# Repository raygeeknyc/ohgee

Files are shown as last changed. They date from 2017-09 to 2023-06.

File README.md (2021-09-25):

# ohgee
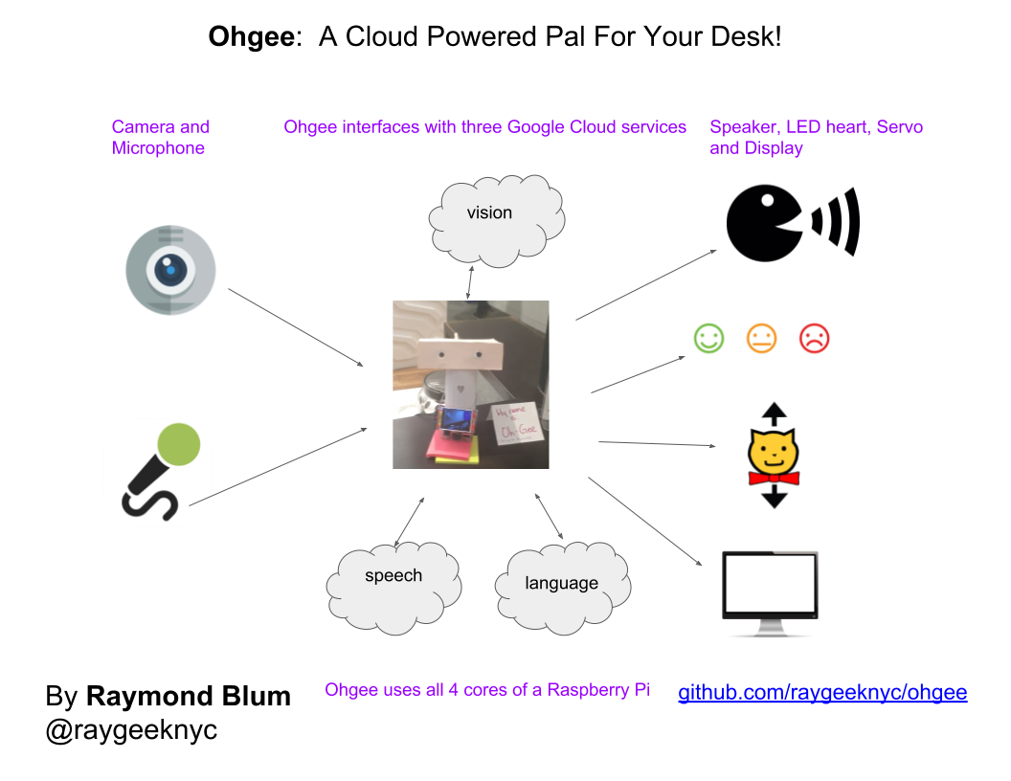
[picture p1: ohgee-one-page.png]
In a nutshell Overview


The OhGee Cloud Services Avatar

A robot that understand speech and face sentiment; it nods, speaks and uses an RGB LED heart to interact with observers.

Ohgee performs local motion detection, sound detection and speech synthesis.

When motion is detected, images are sent to the [Google Cloud Vision service](https://cloud.google.com/vision/) for object detection and labelling.

When sound is detected, the audio stream is sent to the [Google Cloud Speech-to-Text service](https://cloud.google.com/speech-to-text/) for speech recognition.

Any speech transcript returned by the speech service is sent to the [Google Cloud Natural Language service](https://cloud.google.com/natural-language/) for analysis.

Analyzed speech is examined for known key phrases and patterns to which Ohgee selects a random response from an associated set of responses.

Analyzed images are checked for some known labels, if any of those labels are present, Ohgee responds with both incredible wit and tact!
The analyzed images are examined for faces - if any faces are found, Ohgee elides each face with a smiley illustrating their detected sentiment.
If a face is "close enough" Ohgee greets the person and bid them farewell when they depart.

Click on the image to see a quick demo...
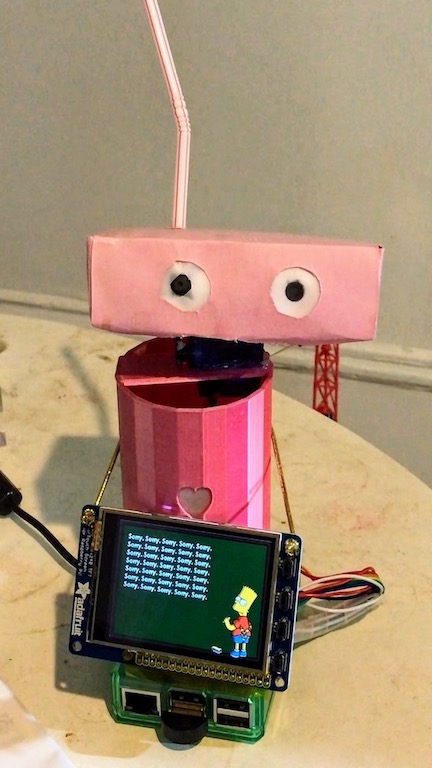
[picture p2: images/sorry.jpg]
demo (https://youtu.be/PBYmpuFzArQ "Ohgee demo")


But wait... there's more!

Since visual and audible "noise" varies widely based on location, Ohgee establishes background levels for sound and motion when starting up.

Ohgee also updates from github at startup and restarts if network connectivity is lost.

Want to know more about any of this? Look at the code!

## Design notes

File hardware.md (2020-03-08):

Screen connections
   * VCC : 3.3V
   * Gnd : ground
   * CS : CEO
   * Reset : GOIO25
   * D/C : GPIO24
   * SDI/MOSI : MOSI
   * SCK : SCLK
   * LED : GPIO23 # default was 18 but that PWM is needed for the Servo
   
Servo connections
   * Gnd : ground
   * VCC : 5V
   * Signal : GPIO18
   
LED connections
   * Anode : 3.3V
   * Red cathode : GPIO2
   * Green cathode : GPIO3
   * Blue cathode : GPIO4

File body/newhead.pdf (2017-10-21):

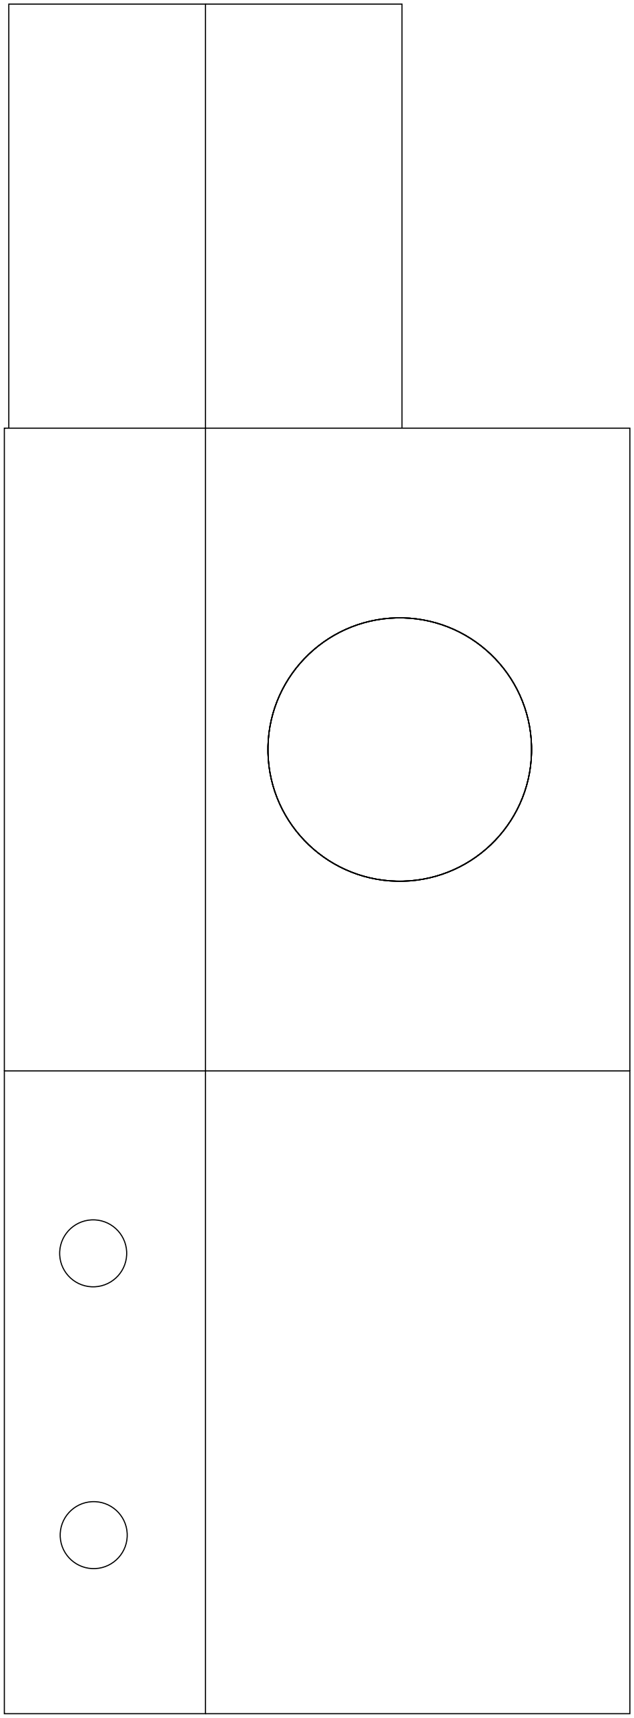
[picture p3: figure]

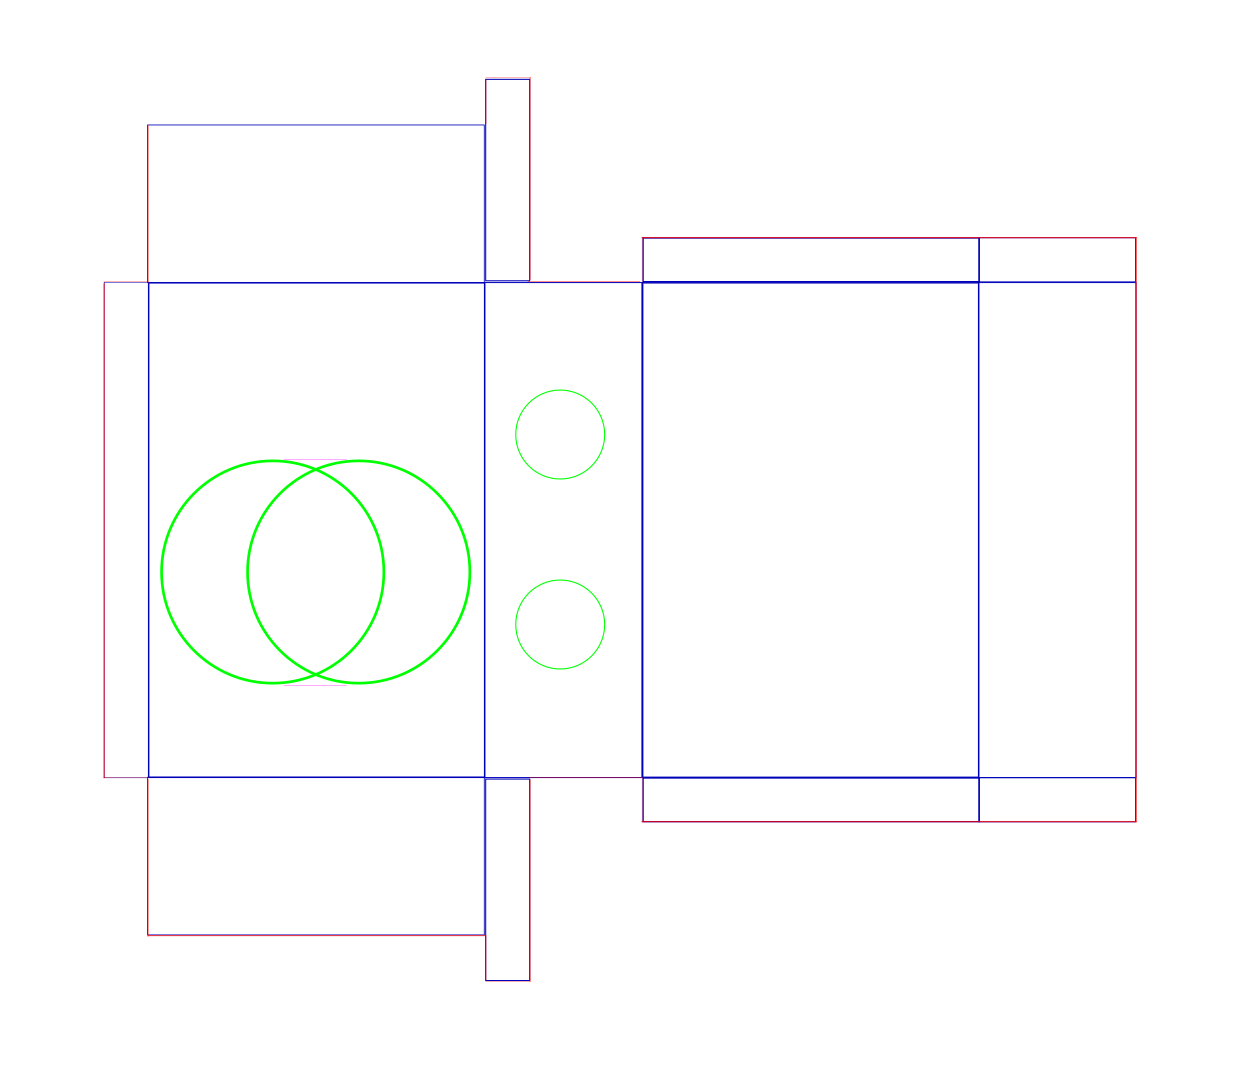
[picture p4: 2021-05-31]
body/ohgeetoo-head.png

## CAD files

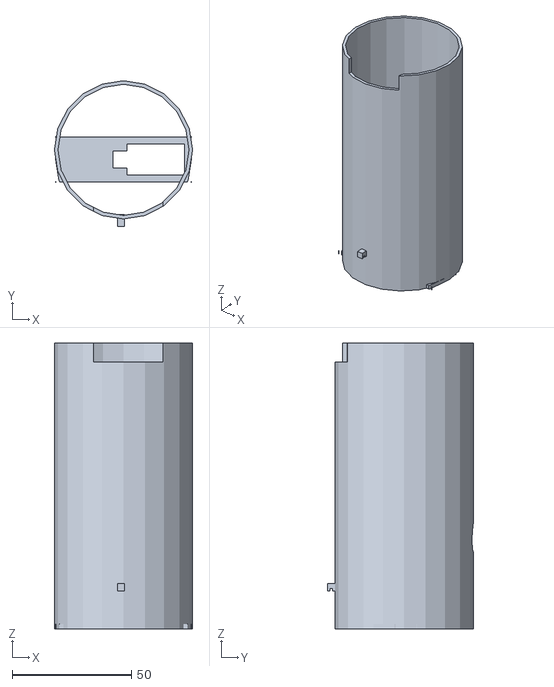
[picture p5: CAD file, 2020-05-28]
body/Ohgee Torso.stl
58.0 x 61.1 x 120.0

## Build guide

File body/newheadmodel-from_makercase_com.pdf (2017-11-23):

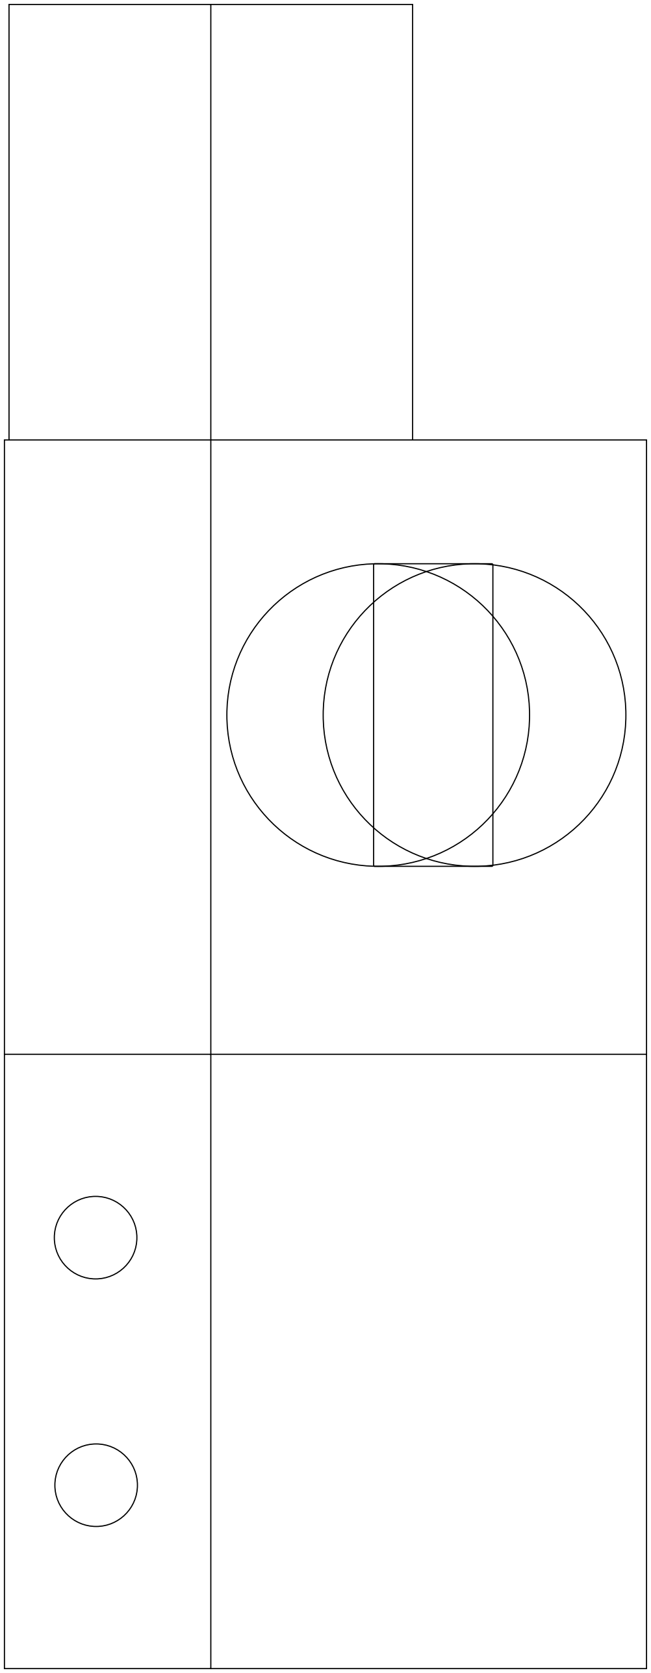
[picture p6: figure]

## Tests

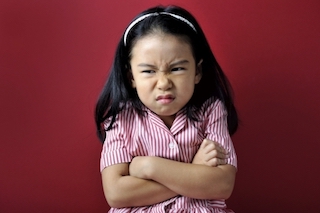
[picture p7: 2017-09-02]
resources/test.jpg

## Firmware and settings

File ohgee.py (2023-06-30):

#!/usr/bin/python3

from versioning import VERSION_ID
import logging

# reorder as appropriate
_DEBUG = logging.INFO
_DEBUG = logging.DEBUG
_DEBUG = logging.WARNING

import tkinter
import PIL
from PIL import ImageTk, Image

import multiprocessing
from multiprocessingloghandler import ParentMultiProcessingLogHandler
import threading
import collections
import RPi.GPIO as GPIO
import time
import io
import sys
import os, signal
import queue

import rgbled
import speechrecognizer
import phraseresponder
import languageanalyzer
import visionanalyzer
import imagesearch

global STOP
STOP = False

global waving
waving = False

DISPLAY_SLEEP_DELAY_SECS = 5 * 60
global mood_set_until
mood_set_until = 0
MOOD_SET_DURATION_SECS = 3
SEARCH_POLL_DELAY_SECS = 0.5
IMAGE_POLL_DELAY_SECS = 0.1
IMAGE_STICKY_DISPLAY_SECS = 3
IMAGE_MIN_DISPLAY_SECS = 0.2
LABEL_RESPONSE_DELAY_SECS = 60.0 * 10

INITIAL_WAKEUP_GREETING = ["I'm", "awake",  "and",  "ready", VERSION_ID]

servoPin = 18
ARM_RELAXED_POSITION = 9
ARM_DOWN_POSITION = 6.0
ARM_UP_POSITION = 11.0
ARM_WAVE_LOWER_SECS = 2
ARM_WAVE_RAISE_SECS = 1
ARM_WAVE_DELAY_SECS = 1
_ARM_SERVO_CATCHUP_SECS = 0.1
MIN_FACE_WAVE_DELAY_SECS = 10

GREETING_INTERVAL_SECS = 5
SEARCH_INTERVAL_SECS = 10

SENTIMENT_DURATION_STIMULUS_FRAMES_THRESHOLD = 3
SENTIMENT_DURATION_STIMULUS_INCREMENT_FACTOR = 2.5

FACE_CLOSENESS_AREA_THRESHOLD = 1.0/10  # A face must be this portion of the frane for us to greet it
SPEECH_TMP_FILE="/tmp/speech.wav"
PICO_CMD='pico2wave -l en-US --wave "%s" "%s";aplay "%s"'
REBOOT_CMD='./reboot.sh'
SCREEN_SLEEP_CMD='./screen_sleep.sh'
SCREEN_WAKE_CMD='./screen_wake.sh'

def getPhraseForSentiment(dominant_sentiment):
  if dominant_sentiment > 0:
    phrase,_ = visionanalyzer.getGoodMoodGreeting()
  elif dominant_sentiment < 0:
    phrase,_ = visionanalyzer.getBadMoodGreeting()
  else:
    phrase = None
  return phrase

def expireMood():
    global mood_set_until
    if mood_set_until and mood_set_until < time.time():
        mood_set_until = 0
        led.setColor(rgbled.OFF)

def setMoodTime():
    global mood_set_until
    global MOOD_SET_DURATION_SECS
    mood_set_until = time.time() + MOOD_SET_DURATION_SECS

def showGoodMood(score):
    logging.debug("Good mood {}".format(score))
    led.setColor(rgbled.GREEN)
    setMoodTime()

def showBadMood(score):
    logging.debug("Bad mood {}".format(score))
    led.setColor(rgbled.RED)
    setMoodTime()

def showMehMood(score):
    logging.debug("Meh mood {}".format(score))
    led.setColor(rgbled.CYAN)
    setMoodTime()

def signal_handler(sig, frame):
    global STOP
    logging.debug("INT signal trapped")
    if STOP:
        logging.debug("Second INT signal trapped, killing")
        signal.signal(signal.SIGINT, signal.SIG_IGN)
        os.kill(os.getpid(), signal.SIGTERM)
    STOP = True
signal.signal(signal.SIGINT, signal_handler)
 
def speak(speech_queue):
    global STOP
    logging.debug("Speaker started")
    while not STOP:
        try:
            logging.debug("Waiting for something to say")
            utterance = " ".join(speech_queue.get())
            logging.debug("Not listening while talking")
            recognition_worker.suspendListening()
            logging.debug("TRACE Saying %s", utterance)
            os.system(PICO_CMD % (SPEECH_TMP_FILE, utterance, SPEECH_TMP_FILE))
            logging.debug("TRACE Done Saying")
        except Exception:
            logging.exception("Error speaking")
        finally:
            logging.debug("Ready to listen")
            recognition_worker.resumeListening()
    logging.debug("Speaker stopping")

def waveArm():
    lowerArm()
    time.sleep(_ARM_SERVO_CATCHUP_SECS)
    arm.ChangeDutyCycle(0)
    time.sleep(ARM_WAVE_LOWER_SECS)
    raiseArm()
    time.sleep(_ARM_SERVO_CATCHUP_SECS)
    arm.ChangeDutyCycle(0)
    time.sleep(ARM_WAVE_RAISE_SECS)
    relaxArm()
    time.sleep(_ARM_SERVO_CATCHUP_SECS)
    arm.ChangeDutyCycle(0)

def wave():
    global waving
    global STOP
    while not STOP:
        while not waving:
            time.sleep(ARM_WAVE_DELAY_SECS)
        logging.debug("Wave")
        waveArm()
        waving = False

def receiveLanguageResults(nl_results, search_queue):
    logging.debug("Listening for language")
    _, nl_results = nl_results
    last_search_at = 0.0
    
    while True:
        try:
            phrase = nl_results.recv()
            text, tokens, entities, sentiment, decorated_noun = phrase
            logging.debug("Got spoken phrase {} noun {}".format(text, decorated_noun))
            if languageanalyzer.isGood(sentiment):
                showGoodMood(sentiment)
            elif languageanalyzer.isBad(sentiment):
                showBadMood(sentiment)
            else:
                showMehMood(sentiment)
            response = phraseresponder.getResponse(text.strip(), entities)
            if response:
                logging.debug("Phrase matched")
                comeback, wave_flag = response
                speech_queue.put(comeback)
                if wave_flag:
                    startWaving()
                if comeback in phraseresponder.REBOOT_RESPONSES:
                    reboot()
            if decorated_noun:
                since_searched = time.time() - last_search_at
                if since_searched > SEARCH_INTERVAL_SECS:
                    logging.info("Searching for images of %s" % str(decorated_noun))
                    search_queue.put(decorated_noun)
                    last_search_at = time.time()
        except EOFError:
            logging.debug("End of NL results queue")
            break
        except Exception:
            logging.exception("Error speaking")
    logging.debug("Done listening")

def watchForVisionResults(vision_results_queue, image_queue):
    logging.debug("Watching")
    _, vision_results_queue = vision_results_queue
    recent_sentiments = collections.deque([0.0, 0.0, 0.0], maxlen=3)
    recent_face_counts = collections.deque([0.0, 0.0, 0.0], maxlen=3)
    
    last_greeting_at = 0.0
    last_wave_at = 0
    dominant_sentiment = -999
    last_label_response_at = time.time()
    prev_recognized_label_text = None
    while True:
        try:
            # Expire memory of the last image label we responded to
            if time.time() > (last_label_response_at + LABEL_RESPONSE_DELAY_SECS):
                prev_recognized_label_text = None
            greeting = None
            wave_flag = False
            feeling_good = False
            feeling_bad = False
            feeling_good_extended = False
            feeling_bad_extended = False
   
            processed_image_results = vision_results_queue.recv()
            processed_image, labels, faces, sentiment, area = processed_image_results
            logging.debug("{} faces detected".format(len(faces)))
            logging.debug("{} sentiment detected".format(sentiment))
            logging.debug("{} largest face".format(area))

            image_queue.put((processed_image, False))
            logging.debug("Put a processed image %s" % id(processed_image))

            if area >= FACE_CLOSENESS_AREA_THRESHOLD:
                if sentiment < 0: sentiment = -1
                if sentiment > 0: sentiment = 1
                face_count = len(faces)
            else:
                sentiment = 0
                face_count = 0
            recent_sentiments.appendleft(sentiment)
            recent_face_counts.appendleft(face_count)
               
            if recent_face_counts[0] == 0 and len(recent_face_counts) > 1 and recent_face_counts[1] > 0:
              logging.debug("Skipping one frame dropout of faces for sentiment tracking")
            else:
              if dominant_sentiment != sentiment:
                sentiment_duration = 0
            dominant_sentiment = sentiment
            sentiment_duration += 1

            if sentiment_duration == SENTIMENT_DURATION_STIMULUS_FRAMES_THRESHOLD:
              greeting = getPhraseForSentiment(dominant_sentiment)
              logging.debug("Got phrase {} for sentiment {}".format(greeting, dominant_sentiment))
              sentiment_reminder_delay = SENTIMENT_DURATION_STIMULUS_FRAMES_THRESHOLD
            elif sentiment_duration > SENTIMENT_DURATION_STIMULUS_FRAMES_THRESHOLD and ((sentiment_duration - SENTIMENT_DURATION_STIMULUS_FRAMES_THRESHOLD) %  sentiment_reminder_delay) == 0:
              greeting = getPhraseForSentiment(dominant_sentiment)
              logging.debug("Got additional phrase {} for sentiment {}".format(greeting, dominant_sentiment))
              sentiment_reminder_delay = int(SENTIMENT_DURATION_STIMULUS_INCREMENT_FACTOR * sentiment_reminder_delay)

            if recent_face_counts[0] > recent_face_counts[1] and recent_face_counts[0] > recent_face_counts[2]:
                logging.debug("Arrival")
                greeting = phraseresponder.getGreeting()
                wave_flag = True
            if recent_face_counts[0] < recent_face_counts[1] and recent_face_counts[0] < recent_face_counts[2] :
                logging.debug("Departure")
                greeting = phraseresponder.getFarewell()

            # Issue a response the first consecutive time we see a set of labels that we know a response to
            image_label_greeting = visionanalyzer.getGreetingForLabels(labels)
            if image_label_greeting and image_label_greeting[0]:
                logging.debug("l: {}  pl: {} g: {}".format(image_label_greeting[2], prev_recognized_label_text, image_label_greeting[0]))
                if image_label_greeting[2] == prev_recognized_label_text:
                    logging.debug("repeated greeting skipped")
                    image_label_greeting = None
                else:
                    prev_recognized_label_text = image_label_greeting[2]
                    last_label_response_at = time.time()
            if image_label_greeting:
                logging.debug("New greeting label matched")
                greeting, wave_flag, _ = image_label_greeting
  
            if greeting:
                if time.time() - last_greeting_at > GREETING_INTERVAL_SECS: 
                    last_greeting_at = time.time()
                    logging.debug("Greeting {} ({})".format(" ".join(greeting), len(greeting)))
                    speech_queue.put(greeting)
            if wave_flag:
                if time.time() - last_wave_at > MIN_FACE_WAVE_DELAY_SECS:
                    last_wave_at = time.time()
                    startWaving()

        except EOFError:
            logging.debug("End of vision queue")
            break
        except Exception:
            logging.exception("Error watching")
    logging.debug("Done watching")

def lowerArm():
    arm.ChangeDutyCycle(ARM_DOWN_POSITION)

def raiseArm():
    arm.ChangeDutyCycle(ARM_UP_POSITION)

def relaxArm():
    arm.ChangeDutyCycle(ARM_RELAXED_POSITION)

def startWaving():
    global waving
    if not waving:
        waving = True

def searchForTermImage(search_term):
    logging.debug("search for: {}".format(search_term))
    image = imagesearch.getTopImage(search_term)
    return image

def searchForObjects(search_queue, image_queue):
    logging.debug("Image search thread started")
    search_term = None
    while not STOP:
        try:
            t = search_queue.get(False)
            logging.debug("Image search queue had an entry")
            search_term = t
        except queue.Empty:
            if not search_term:
                logging.debug("Empty search queue, waiting")
                time.sleep(SEARCH_POLL_DELAY_SECS)
                continue
            logging.debug("Image search term {}".format(search_term))
            top_image = searchForTermImage(search_term)
            if top_image:
                image_queue.put((top_image, True))
                logging.debug("Put image on display queue")
            search_term = None
        except Exception:
            logging.exception("error searching")
    logging.debug("done searching")

def sleepDisplay():
    try:
        os.system(SCREEN_SLEEP_CMD)
    except Exception:
        logging.exception("Error putting display to sleep")

def reboot():
    try:
        os.system(REBOOT_CMD)
    except Exception:
        logging.exception("Error rebooting on command")

def wakeDisplay():
    try:
        os.system(SCREEN_WAKE_CMD)
    except Exception:
        logging.exception("Error waking display from sleep")

def maintainDisplay(root_window, image_queue):
    last_image_at = time.time()
    display_off = False
    canvas = tkinter.Canvas(root_window, width=root_window.winfo_screenwidth(), height=root_window.winfo_screenheight())
    canvas.pack()
    image = None
    tk_image = None
    skipped_images = 0
    while not STOP:
        try:
            try:
                show_image = False
                if (not display_off) and ((time.time() - last_image_at) > DISPLAY_SLEEP_DELAY_SECS):
                    display_off = True
                    sleepDisplay()
                t = image_queue.get(False)
                logging.debug("Image queue had an entry")
                image, sticky = t
                logging.debug("image %s" % id(image))
                if sticky:
                    logging.debug("got a sticky image")
                    show_image = True
                    image_display_min_secs = IMAGE_STICKY_DISPLAY_SECS
                else:
                    skipped_images += 1
            except queue.Empty:
                if not image:
                    logging.debug("Empty image queue, waiting")
                    skipped_images = 0
                    time.sleep(IMAGE_POLL_DELAY_SECS)
                else:
                    skipped_images -= 1
                    show_image = True
                    image_display_min_secs = IMAGE_MIN_DISPLAY_SECS
                    logging.debug("got the most recent image, skipped over {} images".format(skipped_images))
            if show_image:
                if display_off:
                    wakeDisplay()
                    display_off = False
                last_image_at = time.time()
                logging.debug("displaying image %s" % id(image))
                buffer = io.BytesIO(image)
                buffer.seek(0)
                image = Image.open(buffer)
                image = image.resize((root_window.winfo_screenwidth(), root_window.winfo_screenheight()))
                prev_frame = tk_image
                tk_image = PIL.ImageTk.PhotoImage(image)
                canvas.create_image(0, 0, image=tk_image, anchor="nw")
                image = None
                logging.debug("displayed image %s" % id(image))
                time.sleep(image_display_min_secs)
        except Exception:
            logging.exception("error displaying")
        finally:
            expireMood()
    logging.info("Stopping image display")
    root_window.quit()
    
if __name__ == '__main__':
    print('starting')
    log_stream = sys.stderr
    log_queue = multiprocessing.Queue(100)
    handler = ParentMultiProcessingLogHandler(logging.StreamHandler(log_stream), log_queue)
    logging.getLogger('').addHandler(handler)
    logging.getLogger('').setLevel(_DEBUG)

    logging.debug('starting')
    logging.debug('setting up display')
    root = tkinter.Tk()
    #root.geometry("%dx%d+%d+%d" % (root.winfo_screenwidth(), root.winfo_screenheight(), 0, 0))
    root.wm_attributes('-fullscreen','true')
    root.wm_attributes('-type', 'splash')
    root.overrideredirect(True)
    root.config(cursor='none')

    logging.debug('setting up LED')
    led = rgbled.RgbLed(rgbled.redPin, rgbled.greenPin, rgbled.bluePin, rgbled.powerPin)
    led.setColor(rgbled.RED)
    time.sleep(rgbled.COLOR_CYCLE_SECS)
    led.setColor(rgbled.MAGENTA)
    time.sleep(rgbled.COLOR_CYCLE_SECS)
    led.setColor(rgbled.BLUE)
    time.sleep(rgbled.COLOR_CYCLE_SECS)
    led.setColor(rgbled.CYAN)
    time.sleep(rgbled.COLOR_CYCLE_SECS)
    led.setColor(rgbled.GREEN)
    time.sleep(rgbled.COLOR_CYCLE_SECS)
    led.setColor(rgbled.YELLOW)
    time.sleep(rgbled.COLOR_CYCLE_SECS)
    led.setColor(rgbled.OFF)

    logging.debug('setting up servo')
    GPIO.setmode(GPIO.BCM)
    GPIO.setup(servoPin, GPIO.OUT)
    arm = GPIO.PWM(servoPin, 50)
    arm.start(0)

    waveArm()

    transcript = multiprocessing.Pipe()
    recognition_worker = speechrecognizer.SpeechRecognizer(transcript, log_queue, logging.getLogger('').getEffectiveLevel())
    logging.debug("Starting speech recognition")
    recognition_worker.start()
    unused, _ = transcript
    unused.close()

    nl_results = multiprocessing.Pipe()
    analysis_worker = languageanalyzer.LanguageAnalyzer(transcript, nl_results, log_queue, logging.getLogger('').getEffectiveLevel())
    logging.debug("Starting speech analysis")
    analysis_worker.start()
    unused, _ = nl_results
    unused.close()

    vision_results_queue = multiprocessing.Pipe()
    vision_worker = visionanalyzer.ImageAnalyzer(vision_results_queue, log_queue, logging.getLogger('').getEffectiveLevel())
    logging.debug("Starting image analysis")
    vision_worker.start()
    unused, _ = vision_results_queue
    unused.close()

    try:
        waver = threading.Thread(target = wave, args=())
        waver.start()

        image_queue = queue.Queue()
        watcher = threading.Thread(target = watchForVisionResults, args=(vision_results_queue, image_queue))
        watcher.start()

        search_queue = queue.Queue()
        searcher = threading.Thread(target = searchForObjects, args=(search_queue, image_queue,))
        searcher.start()

        speech_queue = queue.Queue()
        speaker = threading.Thread(target = speak, args=(speech_queue,))
        speaker.start()
        
        listener = threading.Thread(target = receiveLanguageResults, args=(nl_results, search_queue,))
        listener.start()

        logging.debug("waiting for speech recognizer")
        recognition_worker.is_ready.wait()
        logging.debug("speech recognizer is ready")
        speech_queue.put(INITIAL_WAKEUP_GREETING)

        #TODO(raymond) Be aware that there's a race condition between maintainDisplay and mainloop
        displayer = threading.Thread(target = maintainDisplay, args=(root, image_queue,))
        displayer.start()

        root.mainloop()
    except Exception as e:
        logging.error("Error in main: {}".format(e))
    finally:
        logging.debug("Ending main")
        vision_worker.stop()
        recognition_worker.stop()
        analysis_worker.stop()
        logging.debug("Waiting for background processes to exit")
        logging.debug("wait for vision")
        vision_worker.join()
        logging.debug("wait for recognition to exit")
        recognition_worker.join()
        logging.debug("wait for analysis to exit")
        analysis_worker.join()
        led.setColor(rgbled.OFF)
        arm.stop()
        GPIO.cleanup()
        logging.debug("Done")
        sys.exit(0)

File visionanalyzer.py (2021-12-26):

#!/usr/bin/python3

import logging
# Used only if this is run as main
_DEBUG = logging.DEBUG

SENTIMENT_CONFIDENCE_THRESHOLD = 0.25
GOOD_SENTIMENT_THRESHOLD = SENTIMENT_CONFIDENCE_THRESHOLD
BAD_SENTIMENT_THRESHOLD = -1*SENTIMENT_CONFIDENCE_THRESHOLD

# Import the packages we need for drawing and displaying images
from PIL import Image, ImageDraw

# Imports the Google Cloud client packages we need
from google.cloud import vision

# Enumerate the likelihood names that are defined by Cloud Vision 1
LIKELIHOOD_NAMES = {'UNKNOWN':0, 'VERY_UNLIKELY':1, 'UNLIKELY':2, 'POSSIBLE':3,
  'LIKELY':4, 'VERY_LIKELY':5}


from picamera import PiCamera

import multiprocessing
from multiprocessingloghandler import ParentMultiProcessingLogHandler
from multiprocessingloghandler import ChildMultiProcessingLogHandler
from random import randint
import io
import sys
import os
import time
import signal
import queue
import threading

# This is the desired resolution of the Pi camera
RESOLUTION = (600, 400)
CAPTURE_RATE_FPS = 2
# This is over an observed covered camera's noise
TRAINING_SAMPLES = 5
# This is how much the green channel has to change to consider a pixel changed
PIXEL_SHIFT_SENSITIVITY = 30
# This is the portion of pixels to compare when detecting motion
MOTION_DETECT_SAMPLE = 1.0/20  # so... 5%? (Kudos to Sarah Cooper)

# This is how long to sleep in various threads between shutdown checks
POLL_SECS = 0.1

# This is the rate at which to send frames to the vision service
ANALYSIS_RATE_FPS = .67
_ANALYSIS_DELAY_SECS = 1.0/ANALYSIS_RATE_FPS

COLOR_MEH = (0, 0, 127)
COLOR_BAD = (200, 0, 0)
COLOR_GOOD = (0, 200, 0)
COLOR_FEATURES = (255,255,255)

def signal_handler(sig, frame):
    global STOP
    if STOP:
        signal.signal(signal.SIGINT, signal.SIG_IGN)
        os.kill(os.getpid(), signal.SIGTERM)
    logging.debug("SIGINT")
    STOP = True
signal.signal(signal.SIGINT, signal_handler)

EMPTY_LABELS = []

BAD_MOOD_GREETINGS = (["don't", "worry", "be", "happy"], ["I'm", "sorry", "that", "you're", "not", "feeling", "happy"], ["You", "look", "down"], ["I", "hope", "that", "I", "can", "cheer", "you", "up"], ["I", "hope", "that", "you", "feel", "better", "soon"], ["Smile!"])

GOOD_MOOD_GREETINGS = (["I'm", "glad", "that", "you", "are", "happy"], ["You", "look", "happy"], ["You", "cheer", "me", "up"], ["It's", "great", "to", "see", "you", "happy"], ["Great", "day"])

DOG_LABELS = ["dog", "canine"]
DOG_GREETINGS = (["here", "doggie"], ["hi","puppy"],  ["hello", "puppy"], ["woof", "woof"], ["bark", "bark"], ["good", "puppy"], ["good", "puppy"], ["nice", "doggie"])

CAT_LABELS = ["cat", "feline"]
CAT_GREETINGS = (["meow"], ["meow", "meow"], ["nice", "kitty"], ["what", "a", "nice", "cat"])

HAT_LABELS = ["hat", "cap", "headgear"]
HAT_GREETINGS = (["that's", "a", "nice", "hat"], ["nice", "hat"], ["nice", "cap"], ["I", "like", "your", "hat"])

COFFEE_LABELS = ["espresso", "cup", "mug", "coffee", "coffee cup", "drinkware"]
COFFEE_GREETINGS = (["is", "that", "a", "cup", "of", "good", "coffee"], ["I", "love", "coffee", "too"], ["I", "hope", "that", "you", "enjoy", "your", "coffee"])

EYEGLASS_LABELS = ["glasses", "eyewear"]
EYEGLASS_GREETINGS = (["those", "are", "nice", "eye", "glasses"], ["I", "like", "your", "glasses"], ["nice", "glasses"], ["nice", "eye", "glasses"], [], [], [], [])

FLOWER_LABELS = ["flowers", "flower", "floral"]
FLOWER_GREETINGS = (["what", "a", "pretty", "flower"], ["nice", "flowers"], [])

# Only the first label found in tags will be used, so prioritize them in this list
LABELS_GREETINGS = [(DOG_LABELS, DOG_GREETINGS, EMPTY_LABELS, True),
  (CAT_LABELS, CAT_GREETINGS, EMPTY_LABELS, False),
  (HAT_LABELS, HAT_GREETINGS, EMPTY_LABELS, False),
  (FLOWER_LABELS, FLOWER_GREETINGS, EMPTY_LABELS, False),
  (COFFEE_LABELS, COFFEE_GREETINGS, EMPTY_LABELS, False),
  (EYEGLASS_LABELS, EYEGLASS_GREETINGS, EMPTY_LABELS, False)]

def randomGreetingFrom(phrases):
    if not phrases: return []
    return phrases[randint(0,len(phrases)-1)]

def getBadMoodGreeting():
    return (randomGreetingFrom(BAD_MOOD_GREETINGS), False)

def getGoodMoodGreeting():
    return (randomGreetingFrom(GOOD_MOOD_GREETINGS), False)

# Return the first label of the set that a match was found in
# but a match was not found in excludes
def getGreetingForLabels(labels):
    for tags, greetings, excludes, wave_flag in LABELS_GREETINGS:
        for label in labels:
            logging.debug("label: {}".format(label))
        matched_label_text = labelMatch(labels, tags)
        if matched_label_text:
            matched_exclude = labelMatch(labels, excludes)
            if not matched_exclude:
                return (randomGreetingFrom(greetings), wave_flag, tags[0])
    return None

def labelMatch(labels,tags):
    for candidate_label in labels:
        if candidate_label in tags:	
            return candidate_label
    return None

# Sentiment is -1, 0 or +1 for this sentiment and level
# -1 == bad, 0 == meh, +1 == good
def getSentimentForLevel(face, level):
    if face.joy_likelihood == level or face.surprise_likelihood == level:
        logging.debug("getSentimentForLevel: %s joy: %s surprise: %s" % (str(level), str(face.joy_likelihood), str(face.surprise_likelihood)))
        return 1.0
    if face.anger_likelihood == level or face.sorrow_likelihood == level:
        logging.debug("getSentimentForLevel: %s anger: %s sorrow: %s" % (str(level), str(face.anger_likelihood), str(face.sorrow_likelihood)))
        return -1.0
    return 0.0

def getSentimentWeightedByLevel(face):
    logging.debug("joy: {}, surprise:{}, anger:{}, sorrow:{}".format(
        face.joy_likelihood, face.surprise_likelihood, face.anger_likelihood, face.sorrow_likelihood))
    sentiment = getSentimentForLevel(face, LIKELIHOOD_NAMES['VERY_LIKELY'])
    if sentiment != 0:
       return sentiment
    sentiment = getSentimentForLevel(face, LIKELIHOOD_NAMES['LIKELY'])
    if sentiment != 0:
       return sentiment * SENTIMENT_CONFIDENCE_THRESHOLD
    sentiment = getSentimentForLevel(face, LIKELIHOOD_NAMES['POSSIBLE'])
    if sentiment != 0:
       return sentiment * SENTIMENT_CONFIDENCE_THRESHOLD
    sentiment = getSentimentForLevel(face, LIKELIHOOD_NAMES['UNLIKELY'])
    if sentiment != 0:
       return sentiment * 0.25
    return 0.0
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

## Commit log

2017-05-21 Put speech processing into a separate thread. Switched to Python logging. Tweaked some thresholds. Performance has suffered with the 3 thread model. I expect this to improve when it is moved to a sep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
2017-05-25 Fixed code to run. Not tested with a live mic.
    [ohgee.py]
2017-06-01 added model of background process with multiple threads Logging is still needed in the background process.
2017-06-02 Process and Thread model for shutdown seems to work but speech processing results are at best sporadic.
2017-06-11 Updated to use my logging module It is dropping single words and recognition is fair but making mistakes
    [ohgee.py, speechprocessor.py]
2017-06-11 Changed sampling rate and frame size to match ../hearmic.py which was outperforming this, the performance has now tanked. There are some fundamental differences between the two.
2017-06-12 Added more logging Changed inter-thread queue to a deque
2017-06-23 Added logging and refined shutdown processing Still sluggish on shutdown of the speech processing thread
2017-06-23 Added logging Refined shutdown semantics Still slugghish on shutdown of speech processing thread
2017-06-24 Cleaned up speechprocessor and ohgee queue part assignment Termination of the speechprocessor thread is still not working
    added speechanalyzer, untested
    [ohgee.py, speechanalyzer.py, speechprocessor.py]
2017-06-24 Connected background processes for speech recognizer and speech analyzer clients There are still problems with the shutdown semantics, observed in the speech recognizer. The analyzer needs to publish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
    [ohgee.py, speechanalyzer.py, speechrecognizer.py]
2017-06-28 Refactored shutdown, renamed some functions. Refactored unneeded threads from the NL client. Still waits for a timeout in the recognizer before terminating.
2017-06-28 Added pause detection and bypassing recognition during pauses Added distinction of empty recognition streams in error handling added available() to fedstream
    shutdown still does not work as I'd like in the speechrecognizer
    [fedstream.py, ohgee.py, speechrecognizer.py]
2017-06-28 Switch recognizer to rely on stream status rather than the input buffer to dispatch work
2017-06-29 Updated to show mood on an RGB LED
2017-06-29 Tweaked and refactored polling delay in main client thread Adjusted silence threshold
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2017-06-29 Added support and setup for a servo to drive the arm not tested and not complete
2017-06-30 Created model of async arm waving thread tested added support and represenatation of greeting and farewell recognition not tested
2017-07-01 Got waving working - not tried with a servo yet
2017-07-01 Working micro servo positions. The servo duty cycle of 0 seems to leave it at its current position.
2017-07-02 Added picotts thread to speak random greetings and farewells
2017-07-04 Tweaked servo settings and fixed wave delay
    [ohgee.py]
2017-07-04 Fixed quoting issues in phrases
    [ohgee.py, speechanalyzer.py]
2017-07-04 Fixed arm positions
2017-07-09 Added vision analyzer current does image capture and motion detection, no image analysis
2017-07-09 Modified to render the text of a document rather than the tokens which are broken up into constituent parts such as "do" "n't" from "don't"
    [ohgee.py, speechanalyzer.py]
2017-07-09 Fixed up some errors Runs but not tested with a working mic
    [speechrecognizer.py, visionanalyzer.py]
2017-07-09 Turned off logging, set greeting delay Logging volume training data Tested on a workstation, not with a servo or LEDs
2017-07-10 Flip camera as it is upside down in the robot
    [visionanalyzer.py]
2017-07-11 Added face counting and sentiment tracking Face counting works, sentiment is not being evaluated correctly
    [ohgee.py, speechanalyzer.py, visionanalyzer.py]
2017-07-11 Trap exceptions that were crashing vision analysis - timeouts should be recoverable
    [visionanalyzer.py]
2017-07-12 Refined arrival and departure detection to avoid blips in presence Finished sentiment tracking, added thresholds, fixed bads assignment of best sentiment for frame untested
    [ohgee.py, visionanalyzer.py]
2017-07-12 Handled execption that had hung the vision capture thread with retries
2017-07-13 Seems to have fixed sentiment tracking
    [ohgee.py, visionanalyzer.py]
2017-07-13 Update visionanalyzer.py
    Fix second tier sentiment acceptance, should not have been the literal
    [visionanalyzer.py]
2017-07-17 Update setup_auth.sh
    move connectivity to the driver script
2017-07-22 Added working pinging phrases Fixed use of random suffixes
    [speechanalyzer.py]
2017-07-23 Added error trapping for display Exceptions - not tested
    [ohgee.py]
2017-07-23 Fixed function ref brought over from rankfaces demo
    [visionanalyzer.py]
2017-07-24 Fix syntax error in operator
    [ohgee.py]
2017-07-25 Increased resolution of the camera which resulted in much better face detection. Changed capture and analysis rates.
2017-07-27 Fix permissions of apt-get Refactored error trapping in speech analysis so that errors in the cloud service API such as quota, won't kill the thread and hang the process
    [ohgee.py, speechanalyzer.py]
2017-07-29 Added reporting of IP address to enable connecting to headless devices. Refactored redirects of shells to be consistent.
2017-08-03 add search term processing, change image freshess
    Add a queue of search terms populated by the results of speech analysis
    Add a new thread to process search terms
    Change maintainDisplay to discard any backlog of images awaiting display, only display the most recent image
2017-08-04 Fixed CSE API usage
    [ohgee.py]
2017-08-05 Fixed reference to phraseresponder fix env var setting
    [ohgee.py]
2017-08-06 Reworked, normalized the queue exhaustion model for images and search terms as performance was not good. This is not tested with a reasonable internet connction.
    [imagesearch.py, ohgee.py]
2017-08-08 Handle errors during silence training
    [speechrecognizer.py]
2017-08-08 Handle content retrieval errors
    [imagesearch.py]
2017-08-09 Cleaned up / improved error handling and recovery in various listener threads untested
    [ohgee.py]
2017-08-09 Fixed broken use of finally to exit added logging of skipped images
    [imagesearch.py, ohgee.py]
2017-08-12 Allowed for different auth and credential files per machine. Changed side effects of setup_auth, allowed error reporting
    [imagesearch.py]
2017-08-13 added 3d print source file for torso No cardboard tubes of a near diameter are available.
    [Ohgee Torso.stl]
2017-08-13 Applied holes to torso Added servo mount for top of torso
    [Ohgee Torso.stl, ohgee servo mount.stl]
2017-08-15 Merghed servo mount with torso Rotated torso to accomodate printing servo mount and to better print the heart cutout
    [Ohgee Torso.stl, ohgee servo mount.stl]
2017-08-21 Fixed obsolete initial seed of silence threshold
    [speechrecognizer.py]
2017-08-21 Changed silence threshold to halfway between min and average samples
2017-08-26 add medium safesearch
    too much NSFW out there
    [imagesearch.py]
2017-08-28 Revised ohgeetoo torso servo mount - Made slot 1mm wider and walls around it thicked as it required gouging and then broke. - Removed useless mounting extension. - Added cutout for gear protrusion.
    [Ohgee Torso.stl]
2017-08-31 Add a small extrusion to hang a front display from
    [Ohgee Torso.stl]
2017-08-31 Elevated model in Tinkercad, it was below the base plane
    [Ohgee Torso.stl]
2017-09-03 Fix silence threshold
    I had put in a quick "fix" for silence detection to raise sensitivity but never went back and fixed the issue; the home unit had streamed 8 days+ audio in 10 calendar days.this is an attempt at a real fix.
    [speechrecognizer.py]
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2017-09-06 Fix shaft phrases
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2017-09-07 Fixed some errors, image is flashing. Debugging needed
    [ohgee.py]
2017-09-07 Added some logging, made small fix that may be a cause of the blinking image bug
    [ohgee.py]
2017-09-08 Fixed frame blinking Adjusted display rates added back some Shaft phrases
    [ohgee.py, phraseresponder.py]
2017-09-11 Make sticky images non-premptable, i.e they always get displayed. Make sticky images display for a different minimum frame time than non-sticky images. Tweak display polling and minimum frame times.
2017-09-16 fix to enhanced feature drawing
    [visionanalyzer.py]
2017-09-16 Added logging of cloud service RPCs Added a reset of the motion detection following posting of an image for analysis
    [speechanalyzer.py, speechrecognizer.py, visionanalyzer.py]
2017-09-20 added some banal prompts and responses
    [Ohgee Torso.stl]
2017-10-14 Modified servo values to ohgeetoo prototype head positions refactored wave function
2017-10-17 remove waving when a face enters or leaves, this removed oscillating head motions of ohgeetoo
    [ohgee.py]
2017-10-17 Add waving at arrivals back in but throttle it to once every N seconds
2017-10-22 Fixed bottom hole to allow for pivot/swing of torso.
2017-10-22 New head design with slot that allows for nodding motion
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2017-10-23 Added correct label for a flower
    [visionanalyzer.py]
2017-11-07 Improved slots for torso
    [Ohgee Torso.stl]
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2017-12-04 Fixed no name handling
    [phraseresponder.py]
2018-02-18 Avoid straining the servo on nods
    [ohgee.py]
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2018-02-18 Adjust servo values - the home ohgee is still straining at the raised position
2018-02-24 Replace face sentiment tracking with decreasing frequency of greetings.
    [ohgee.py]
2018-02-24 Fixed new sentiment tracking and responses
    [ohgee.py]
2018-02-24 Avoiding repeating label responses
    [ohgee.py]
2018-02-25 Fixes to the label greeting code
    [ohgee.py, visionanalyzer.py]
2018-03-01 Fixed tracking of last label response time
    [ohgee.py]
2018-03-01 Fixed last label response expiration
    [ohgee.py]
2018-03-02 Fix pronounciation of the Hoff
    [phraseresponder.py]
2018-03-05 Fixed detection of repeated greetings. It loses a new label response if it's too soon after the last greeting.
    [ohgee.py, visionanalyzer.py]
2018-03-05 Add exclude labels to label matching add problematic matches to coffee excludes
    [ohgee.py, visionanalyzer.py]
2018-03-12 Fix pronunciation of Hola update version string
    [ohgee.py, phraseresponder.py]
2018-04-08 Fix pronunciation of ohgee
    [phraseresponder.py]
2018-04-10 Fixed order of prompt evaluation
    [phraseresponder.py]
2018-05-08 Fix typo from refactoring
    [visionanalyzer.py]
2018-05-14 Fix pronunciation of a joke
    [phraseresponder.py]
2018-06-08 Added framework for screen timeout untested incremented version to 18
2018-06-12 Fixed detection of pending jobs - the current job is found
2018-06-26 Add commands to power HDMI on and off Still need to add commands for the small TFT
2018-07-05 Make the network monitor more patient as it was rebooting the home unit with a flow network connection, too aggressively
2018-07-05 Fix error handling of image fetch exceptions that I think is leading to gray screens
    [imagesearch.py]
2018-07-15 Added reboot command incremented version to 22
    [ohgee.py, phraseresponder.py]
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2018-09-13 Fixed broken image search results
    [imagesearch.py, ohgee.py]
2018-10-21 Fix capture increment version number
    [ohgee.py, visionanalyzer.py]
2018-10-21 Fix motion detection threshold check
    [visionanalyzer.py]
2019-04-27 Add new template for ohgeetoo head - one sheet not finished aligning cut and score outlines
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2020-03-10 Update phraseresponder.py
    add reboot prompt
    [phraseresponder.py]
2020-03-11 Update ohgee.py
    react to all reboot responses
    [ohgee.py]
2020-03-11 Update phraseresponder.py
    add reboot responses
    [phraseresponder.py]
2020-05-28 Uodated torso to have a larger cable window
    [Ohgee Torso.stl]
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2020-05-30 Fix version string update servo positions
    [ohgee.py]
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2021-05-24 More python3 changes failing on free()
    [fedstream.py, imagesearch.py, multiprocessingloghandler.py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]
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2021-05-29 More API updates Not working - FedStream is not a fit for the API usage adopted here
    [speechrecognizer.py]
2021-05-31 Add microphone module speechrecognizer is not working with microphonestream logging is not working added png of head
    [processmodel.py, speechrecognizer.py]
2021-05-31 Refactored microphone to work more as objects, independent of with contexts working but speechrecognizer standalone fails auth
    [speechrecognizer.py]
2021-06-01 Started recognizing but an error in the use of the audio generator
    [speechrecognizer.py]
2021-06-02 Began replacement speechrecognizer in streaming_recognizer
    [speechrecognizer.py]
2021-06-03 Renamed speecanalyzer
    Reverted to earlier speechrecognizer, made Python3 changes, added error threshold to recognition
    untried
    [languageanalyzer.py, ohgee.py, speechrecognizer.py]
2021-06-05 Various fixed Vision and speech are working speechrecognizer works standalone but gets TIMEOUT errors from within ohgee RGB LED does not seem to be working
    [ohgee.py, speechrecognizer.py, visionanalyzer.py]
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2021-06-10 Added sync of speechrecognizer and ohgee main process
    Reduced potential race of display threads in main process
2021-06-11 Fixed Auggie name recogition Added protection against null content that was encountered
    [imagesearch.py, phraseresponder.py]
2021-06-13 Track continuous unpaused listening
    if continuous listening passes a threshold, suspend listening and mark the recognizer as not ready while retraining the silence threshold
    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
2021-06-13 Working on handling long audio streams and retraining when requests fail not fully tested
    [ohgee.py, speechrecognizer.py]
2021-06-13 Fixed latent bug recently introduced in imagesearch
    [imagesearch.py]
2021-06-14 still debugging audio stream error handling
    [ohgee.py, speechrecognizer.py]
2021-06-14 Pausing seems to work error recovery from audio seems to be working reduced logging level
    [ohgee.py, speechrecognizer.py]
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2021-07-02 Update ohgee.py
    Update servo positions and sequence for Auggie's Ohgee
    Update version number
2021-07-02 Fix binding of conditions to avoid None method call.
    [imagesearch.py]
2021-10-05 Some cleanup of SpeechRecognizer constructor, error found trying to run standalone Fixing standalone, not working
    [speechrecognizer.py]
2021-10-06 Refactor retrain and retry logic as there was too much time spent retraining
    [speechrecognizer.py]
2021-10-15 Added named wilcard token support to phrasematching This is not yet used in response building
    changed some names for clarity
    There is an existing bug in phraseresponder - repeated first words of known phrases do not work,
    wilcards in the first position must match the first position to work
    [phraseresponder.py]
2021-10-15 Refactored friends to use wildcards fixed some logging, still not logging as expected Fixed spaces around results transcripts
    [ohgee.py, phraseresponder.py]
2021-10-15 Worked around bug in phraseresponder
    [phraseresponder.py]
2021-10-17 Fixed embedded phrase matching Cleaned up some logging tested
    Bumped version number
    [ohgee.py, phraseresponder.py]
2021-10-17 Fixed up and reordered content of phrases
    [phraseresponder.py]
2021-10-19 fixed order of candidate phrases bumped version
    [ohgee.py, phraseresponder.py]
2021-10-22 Fixed new phrase syntax
    [phraseresponder.py]
2021-10-22 Fixed same phrase's syntax
    [phraseresponder.py]
2021-10-30 Removed some logging constraints to invesigate failures of display in the Google reception area
    [ohgee.py]
2021-10-30 Moved last log to /boot partition so it can be mounted on a Mac
2021-12-26 Correct nulling of frame, possibly fixing regular failure of the image display thread in the CHEL Ohgee
    [ohgee.py, visionanalyzer.py]
2021-12-26 Revert nulling of frame which prevented frame analysis some logging changes and refactored error handling
    [visionanalyzer.py]
